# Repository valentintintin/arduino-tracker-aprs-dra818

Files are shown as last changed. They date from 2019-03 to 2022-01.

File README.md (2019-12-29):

# GPS tracker on Ham radio APRS network with DRA818 module

## The projet

Inspiration : https://github.com/Toni43/MiniSmartTracker

### Hardware parts used
- Arduino [Nano](https://store.arduino.cc/arduino-nano)
- GPS Module ([NEO 6M](https://www.amazon.fr/NEO-6M-GPS-module-puissance-GY-GPS6MV2/dp/B01ICYA4QU))
- VHF TX module ([DRA818V](http://www.dorji.com/docs/data/DRA818V.pdf))

### Software parts used
- [PlatformIO](https://platformio.org/)
- [QAPRS lib](https://bitbucket.org/valentintintin/arduinoqaprs/) from Lukasz SQ5RWU, forked by me to add PWM
- [TinyGPS+ lib](http://arduiniana.org/libraries/tinygpsplus/)
- [DRA818 lib](https://github.com/fatpat/arduino-dra818) from Jereme Loyet
- [EasyButton](https://github.com/evert-arias/EasyButton) from Evert Arias 

### The circuit

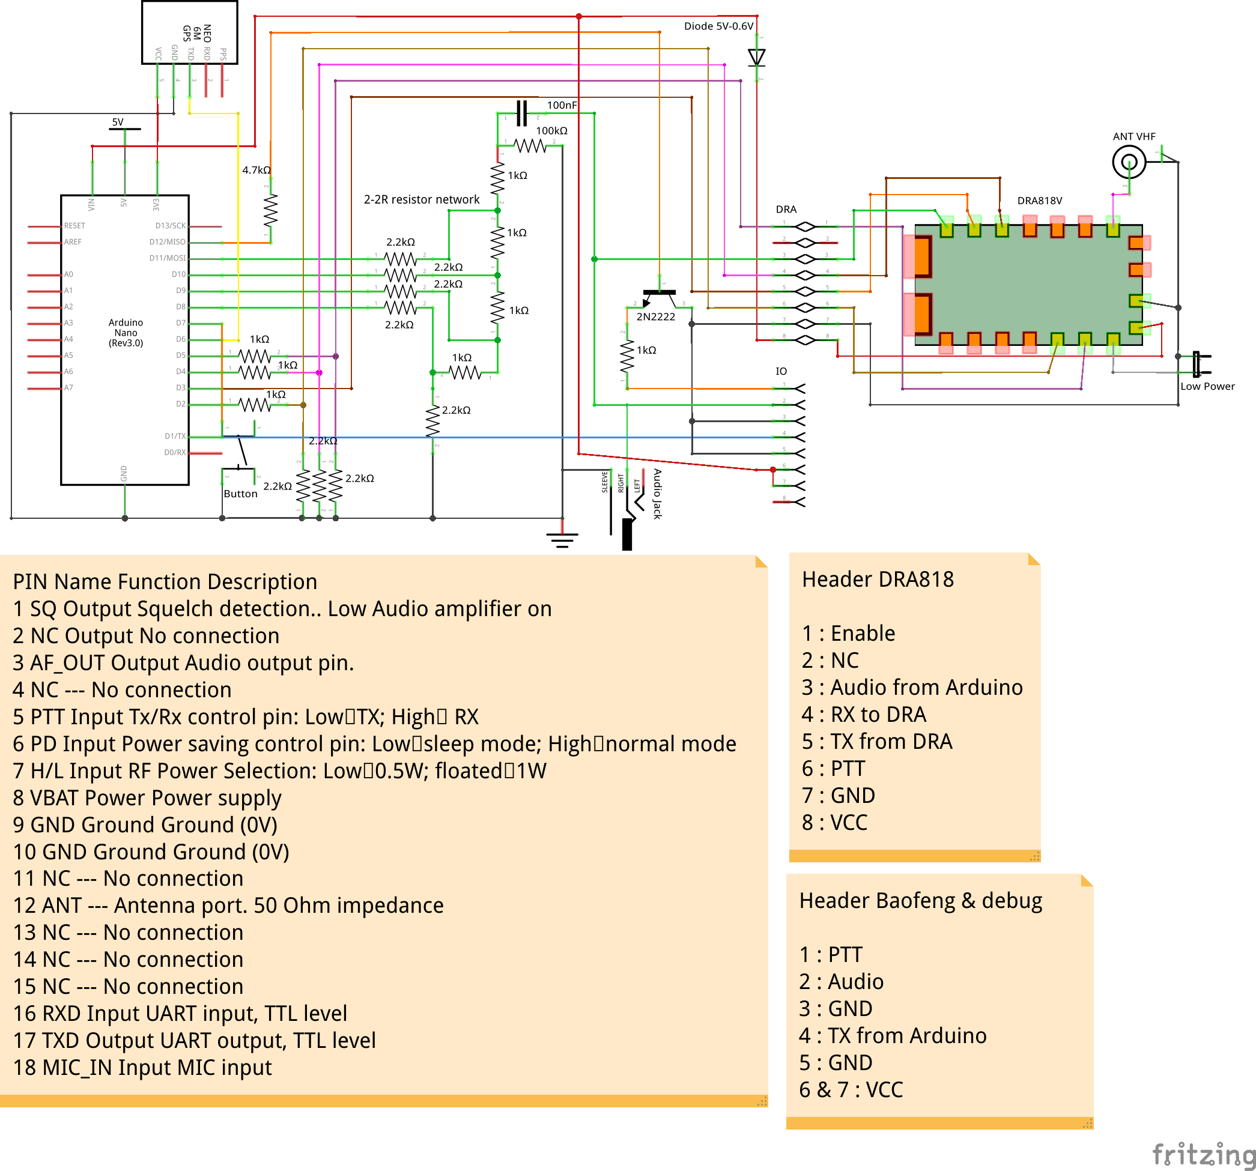
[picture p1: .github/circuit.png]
The circuit


### The Arduino program

The project has one main function : **send its GPS coordinate on ham radio APRS network**.
To accomplish that it has 3 ways :
- With the DRA818V module
- With a Baofeng UV5-R/UVB5 etc connected to the board
- With an external TX by the jack connector

### Compile and run

I use PlatformIO insted of the Arduino IDE.

1. Install [PlatformIO](https://docs.platformio.org/en/latest/installation.html)
2. Run `git clone https://github.com/valentintintin/arduino-tracker-aprs-dra818.git && cd arduino-tracker-aprs-dra818`
3. You have to uncomment `APRS_HW_TYPE_R2R` or `APRS_HW_TYPE_PWM` and comment all the others in `.piolibdeps/ArduinoQAPRS/ArduinoQAPRS.h`
4. Plug your Arduino nano
5. Run `pio run --target upload -e nanoprod`

##### Notes

- There are 2 environments : `nanoprod` without any logs, `nanotest` or with log and APRS sended every time even if no GPS locked.
- The QAPRS lib use a **R2R resistor network** to generate the sound signal or **PWM if you change the circuit and small part of code**. 
- There are many board for DRA818  ([by Handiko](https://github.com/handiko/Dorji-TX-Shield), [by SV1AFN](https://www.sv1afn.com/dra818.html), [by HamShop.cz](https://www.hamshop.cz/avr-arduino-raspberry-pi-c16/vhf-transceiver-module-134174mhz-1w-dra818v-i266/)).
- In boards, Low Pass filter is not always included, **it's recommended to add one**
- To debug I use the button and the TX pin from Arduino with a [M5 Stack](https://m5stack.com/) with my [Logger Project](https://github.com/valentintintin/m5-serial-logger)

#### Program flow

1. At the startup, the Arduino try to detect if there is a DRA818 module plugged. If the connexion failed, it goes to the Baofeng mode.
    - *The sound (AFSK) is always present on the jack connector and on Baofeng header pins. We don't have to use multiple options at the same time because sound "intensity" will decrease.*
    - If you want to start in *test mode* (no guard for GPS fix or TX rate), keep pressed the button at startup
2. If the GPS is locked AND time between TX is reached ==> send the new location. The time between TX is defined by the speed and two affine functions.
3. Keep pressed the button to send your position (if GPS fix) manually

### Photos

| | | | |
|:---:|:---:|:---:|:---:|
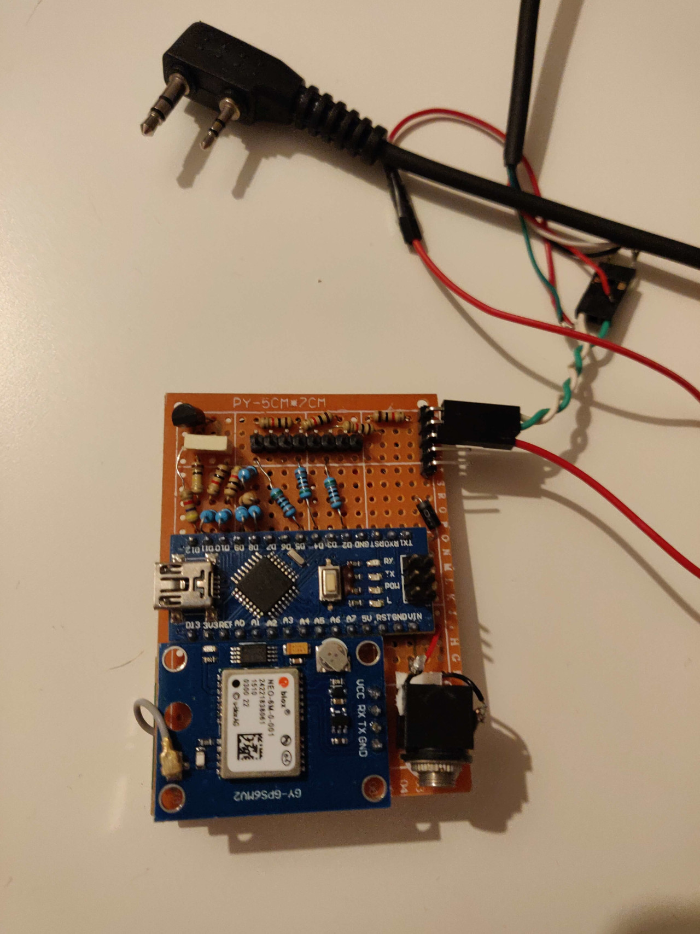
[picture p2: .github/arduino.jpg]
Arduino circuit
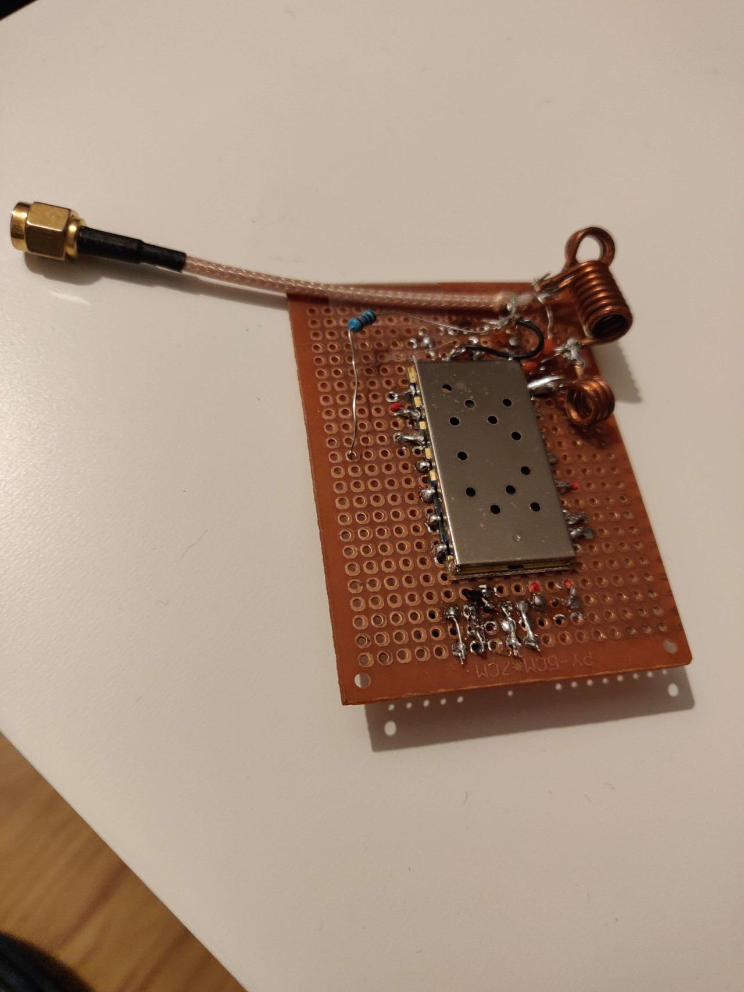
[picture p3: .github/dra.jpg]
DRA818V circuit
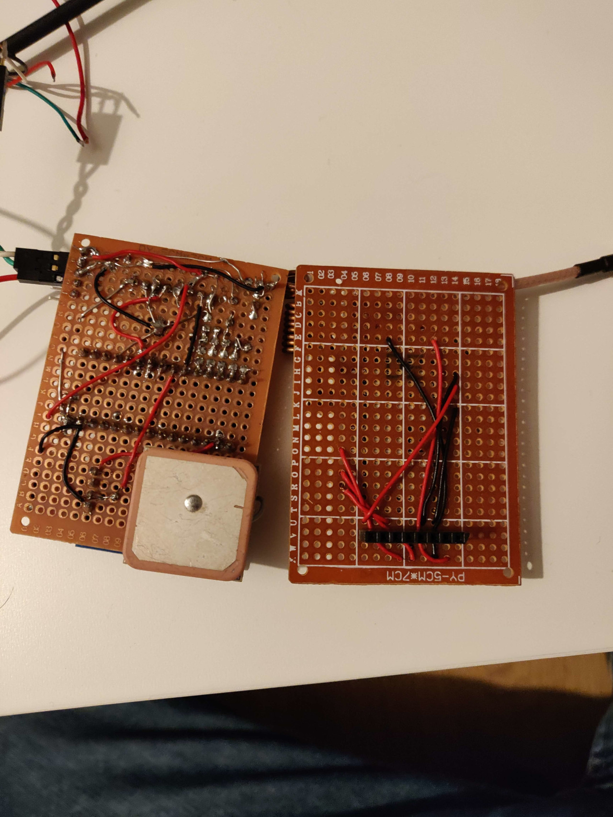
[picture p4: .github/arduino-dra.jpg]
Arduino and DRA818 circuit back
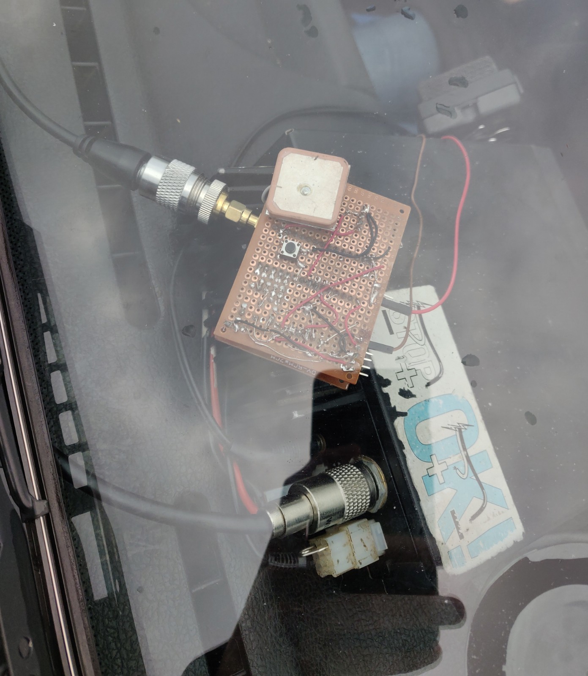
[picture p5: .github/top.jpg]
Arduino and DRA818 circuit from top of my car
|  |  ||

### Test

I did a real test of my project (65 Km * 2 round-trip). I bought an antenna VHF/UHF [Sirio 2070H](https://www.crtfrance.com/fr/systeme-pl/126-hp-2070-h-sirio-mobiles-antenne-mobile.html).

Results from [aprs.fi](https://aprs.fi/) are surprising ! With only 1 Watt, [F5ZFL-4](https://aprs.fi/info/a/F5ZFL-4) at 81Km of my position received one frame !
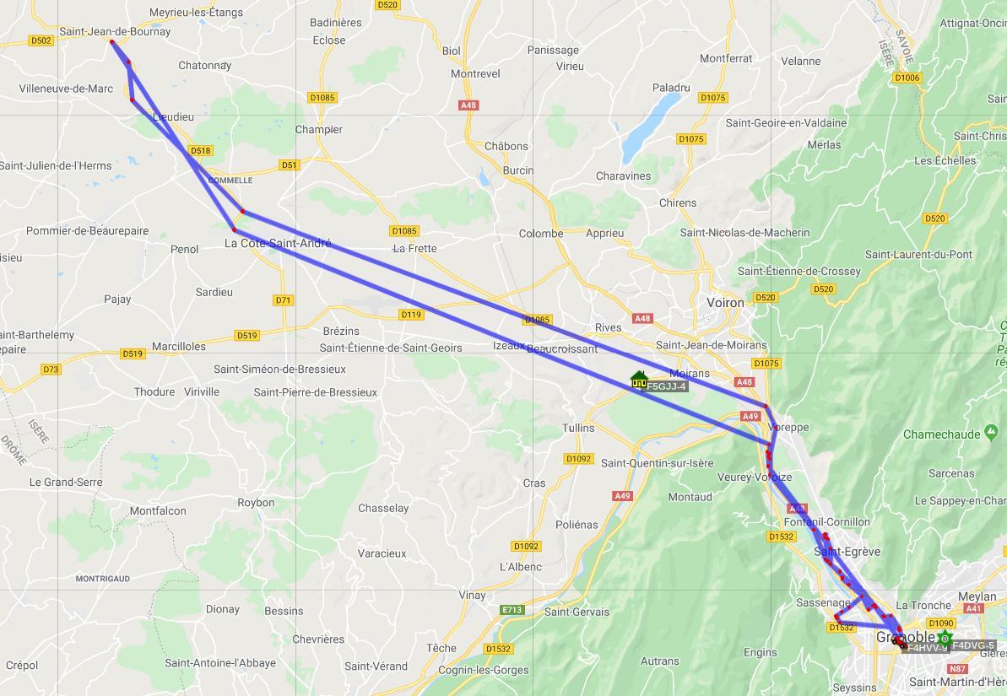
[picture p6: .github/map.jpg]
Results from aprs.fi


## The author

My name is Valentin and my callsign is F4HVV.
I'm not good in electronics but I can do such project working approximately :)

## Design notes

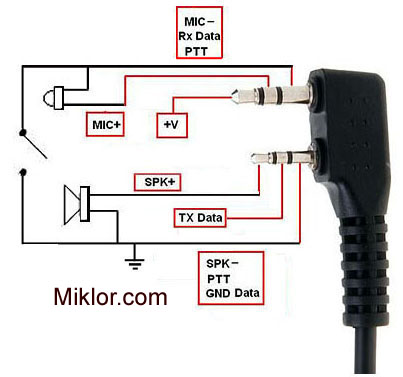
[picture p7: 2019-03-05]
.github/baofeng-pinout-mic.jpg

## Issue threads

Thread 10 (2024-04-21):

Support LGT8F328

Vitaliy86, 2024-04-21:
May be change code for support LGT8F328?

valentintintin, 2024-04-21:
Wow nice board ! But I do not have one.
Maybe you can change the code by yourself. There is a chance if you're lucky that everything works well :)
On my side, I don't use this project anymore. Currently LoRa is better in my region

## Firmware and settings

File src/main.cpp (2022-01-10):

#include <Arduino.h>
#include "Utils.h"
#include "GPS.h"
#include "DRA.h"
#include "APRS.h"

#ifdef USE_BUTTON
    #include <EasyButton.h>
#endif

#ifdef CONTINUE_TX
    #include <ArduinoQAPRS.h>
#endif

#ifdef TEST
#define TX_FREQ 144.600
#define APRS_COMMENT " MODE TEST https://frama.link/arduino-aprs"
#else
#define TX_FREQ 144.800
#define APRS_COMMENT " https://frama.link/arduino-aprs"
#endif

#define DRA_PTT 2
#define TX_GPS 6 // from GPS to Arduino
#define TX_DRA 3 // from DRA to Arduino
#define RX_DRA 4 // from Arduino to DRA
#define DRA_ACTIVE 5
#define PTT_OUT 12
#define BUTTON 7

char CALL[] = "F4HVV";
uint8_t callSsid = '9'; // car
char TO_CALL[] = "APFD38"; // AP = AP Packet + F = France + D38 = department 38 in France
uint8_t TO_CALL_ID = '0';
char RELAYS[] = "WIDE1-1,WIDE2-2";

bool isTestMode = IS_TEST_MODE;

GPS gps(TX_GPS);
DRA dra(TX_DRA, RX_DRA, DRA_PTT, DRA_ACTIVE);
APRS aprs(&dra, &gps, PTT_OUT);

#ifdef USE_BUTTON
    EasyButton button(BUTTON);
#endif

void setup() {
    pinMode(LED_BUILTIN, OUTPUT);
    pinMode(BUTTON, INPUT_PULLUP);

    Serial.begin(115200);

    DPRINTLN(F("Starting ..."));

#ifdef USE_BUTTON
    button.begin();
    button.read();

    if (button.isPressed()) {
        isTestMode = !isTestMode;
        blink(3 + isTestMode);
    }
#endif

#ifdef TX_30_S
    DPRINTLN(F("TX every 30 seconds when GPS fixed"));
#endif

    if (!dra.init(TX_FREQ)) {
        callSsid = '7'; // walk
    }

    aprs.init(CALL, callSsid, TO_CALL, TO_CALL_ID, RELAYS);

    aprs.setComment(APRS_COMMENT);

    DPRINT(F("Test mode: ")); DPRINTLN(isTestMode);
    DPRINT(F("Call: ")); DPRINT(CALL); DPRINT(F("-")); DPRINTLN(callSsid);
    DPRINT(F("Relay: ")); DPRINTLN(RELAYS);
    DPRINT(F("Frequency: ")); DPRINTLN(TX_FREQ);
    DPRINT(F("Comment: ")); DPRINTLN(APRS_COMMENT);

    DPRINTLN(F("Started !"));

#ifdef CONTINUE_TX
    dra.tx();
    digitalWrite(PTT_OUT, HIGH);
    char* bufferAx25 = "F4HVV test de F4HVV test";
    while (true) {
        QAPRS.sendData(bufferAx25);
    }
#endif

#ifdef USE_BUTTON
    button.onPressedFor(5000, []() {
        DPRINTLN(F("TX Forced"));
        aprs.sendIfPossible(isTestMode, true);
    });
#endif
}

void loop() {
#ifdef USE_BUTTON
    button.read();
#endif
    aprs.sendIfPossible(isTestMode, isTestMode);
}

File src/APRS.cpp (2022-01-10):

#include <ArduinoQAPRS.h>
#include "APRS.h"
#include "Utils.h"

APRS::APRS(DRA *dra, GPS *gps, uint8_t txPin) : dra(dra), gps(gps), txPin(txPin) {
    pinMode(txPin, OUTPUT);
    packetBuffer.reserve(255);
}

void APRS::init(char *call, uint8_t callId, char *toCall, uint8_t toCallId, char *relays) {
    QAPRS.init(0, 0, call, callId, toCall, toCallId, relays);
}

bool APRS::txToRadio() {
    DPRINTLN(F("TX ..."));

    digitalWrite(LED_BUILTIN, HIGH);
    if (!dra->isDraDetected()) {
        digitalWrite(txPin, HIGH);
        delay(TIME_TOGGLE_PTT);
    } else {
        dra->tx();
    }

    delay(500);

    DPRINTLN(F("Packet sending"));

    bool qaprsOk = QAPRS.sendData((char *) packetBuffer.c_str()) == QAPRSReturnOK;

    DPRINTLN(F("Packet sent"));

    delay(500);

    digitalWrite(LED_BUILTIN, LOW);
    if (!dra->isDraDetected()) {
        digitalWrite(txPin, LOW);
        delay(TIME_TOGGLE_PTT);
    } else {
        dra->stopTx();
    }

    if (qaprsOk) {
        DPRINTLN(F("TX OK"));
    } else {
        DPRINTLN(F("TX FAILED"));
    }

    return qaprsOk;
}

void APRS::setComment(String comment) {
    this->comment = comment;
}

bool APRS::sendIfPossible(bool forceGps, bool forceTx) {
    if (gps->getData() || forceGps) {
        if (millis() - lastTx >= (uint32_t) 1000 * getTimeSecondsForGivenSpeed() || forceTx) {
            if (sendPosition()) {
                blink(2);
                lastTx = millis();
                lastSpeed = gps->gps.speed.kmph();
                return true;
            }
        }
        blink(1);

        DPRINT(F("Next: ")); DPRINT((uint32_t) abs(getTimeSecondsForGivenSpeed() - ((millis() - lastTx) / 1000)));
        DPRINT(F("/")); DPRINTLN(getTimeSecondsForGivenSpeed());

        return false;
    } else {
        lastTx = 0;
        lastSpeed = 0;
        blink(5);
        return false;
    }
}

#pragma clang diagnostic push
#pragma ide diagnostic ignored "hicpp-signed-bitwise"
long APRS::readVccAtmega() {
    long result;  // Read 1.1V reference against AVcc
    ADMUX = _BV(REFS0) | _BV(MUX3) | _BV(MUX2) | _BV(MUX1);
    delay(2);             // Wait for Vref to settle
    ADCSRA |= _BV(ADSC);  // Convert
    while (bit_is_set(ADCSRA, ADSC));
    result = ADCL;
    result |= ADCH << 8;
    result = 1126400L / result;  // Back-calculate AVcc in mV
    return result;
}
#pragma clang diagnostic pop

uint16_t APRS::getTimeSecondsForGivenSpeed() {
#ifdef TX_30_S
    return 30;
#endif

    float speed = gps->gps.speed.kmph();
    if (speed >= 20) {
        return -0.1 * speed + 42;
    } else if (speed >= 5) {
        return -11 * speed + 230;
    } else if (lastSpeed >= 20 || lastTx == 0) {
        return 0;
    } else {
        return 300;
    }
}

float APRS::convertDegMin(float decDeg) {
    float DegMin;

    int intDeg = (int) decDeg;               // partie entière
    decDeg -= (float) intDeg;                  // partie décimale
    decDeg *= 60;                      // décimale * 60
    DegMin = (float) (intDeg * 100) + decDeg;  // entière * 100 + décimale

    return DegMin;
}

void APRS::stringPadding(int number, byte width, String *dest) {
    int temp = number;
    if (!temp) {
        temp++;
    }

    for (int i = 0; i < width - (log10(temp)) - 1; i++) {
        dest->concat('0');
    }
    dest->concat(number);
}

void APRS::stringPaddingf(float number, byte width, String *dest) {
    float temp = number;
    if (temp == 0) {
        temp++;
    }

    for (int i = 0; i < width - (log10(temp)) - 1; i++) { // NOLINT(performance-type-promotion-in-math-fn)
        dest->concat('0');
    }
    dest->concat(number);
}

void APRS::buildPacket() {
    auto lat = (float) gps->gps.location.lat();
    auto lng = (float) gps->gps.location.lng();
    float latDegMin = convertDegMin(lat);
    float lngDegMin = convertDegMin(lng);

    packetBuffer.remove(0, packetBuffer.length());

    // Start coordinates
    packetBuffer += '!';

    // Latitude
    stringPaddingf(latDegMin, 4, &packetBuffer);
    // Determine N or S
    if (latDegMin >= 0) {
        packetBuffer += 'N';
    } else if (latDegMin < 0) {
        packetBuffer += 'N';
    }

    // Separator
    packetBuffer += '/';

    // Longitude
    stringPaddingf(lngDegMin, 5, &packetBuffer);
    // Determine E or W
    if (lngDegMin >= 0) {
        packetBuffer += 'E';
    } else if (lngDegMin < 0) {
        packetBuffer += 'W';
    }

    if (dra->isDraDetected()) {
        // Symbol car
        packetBuffer += '>';
    } else {
        // Symbol human
        packetBuffer += '[';
    }

    // North orientation
    stringPadding((int) gps->gps.course.deg(), 3, &packetBuffer);
    // Separator
    packetBuffer += '/';
    // Speed
    stringPadding((int) gps->gps.speed.knots(), 3, &packetBuffer);
    // Altitude
    packetBuffer += "/A=";
    stringPadding((int) gps->gps.altitude.feet(), 6, &packetBuffer);
    // Voltage
    packetBuffer += "/V=";
    packetBuffer += (float) readVccAtmega() / 1000.f;
    // Accuracy
    packetBuffer += " HDOP=";
    packetBuffer += (int) gps->gps.hdop.hdop();
    // Comment
    if (comment.length()) {
        packetBuffer += comment;
    }

    DPRINT(F("Packet : "));
    DPRINTLN(packetBuffer);
}

bool APRS::sendPosition() {
    buildPacket();
    return txToRadio();
}

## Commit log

2018-12-04 [Update] Begin debug PIN for DRA transmit test
2018-12-12 [Fix] GPS lib fix (pojnter)
    [APRS.cpp, DRA.cpp]
2018-12-12 [Fix] TX issue. WIP
    [APRS.cpp, DRA.cpp, main.cpp]
2018-12-12 [Fix] Char type variable APRS + GPS QAPRS init bug
    [APRS.cpp, main.cpp]
2019-05-31 :work: unint everywhere + distance between TX + DRA Start with PTT + DRA Sleep
    [trackerAPRS.fzz]
2019-07-27 :bug: Try to fix a bug (always sending)
    [APRS.cpp, main.cpp]
2019-07-27 :memo: Add R2R mention + few notes
    [trackerAPRS.fzz]
2019-07-27 :green_heart: Fix syntax error
    [APRS.cpp]
2019-07-27 :camera_flash: Add photos
2019-09-08 :ambulance: Patch #3 (not a fix !)
    [APRS.cpp]
2019-09-17 :green_heart: Close #8
    [trackerAPRS.fzz]
2019-09-18 :ok_hand: Updating pin TX/RX DRA name #8
2019-09-22 :ambulance: Fix loop issue again
    [APRS.cpp, main.cpp]
2019-12-23 :boom: Too much changes #1 SmartTX + Logger + button
    [aprs speed time.ods]
2019-12-29 :memo: Update README
    [trackerAPRS.fzz]
